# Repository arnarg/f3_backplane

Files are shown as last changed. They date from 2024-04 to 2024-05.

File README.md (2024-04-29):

# F3 Backplane

> F2 + 1 = F3, right?

This is a custom backplane PCB for Terramaster F2-221, which adds a socket for an NVMe SSD for booting an operating system from.

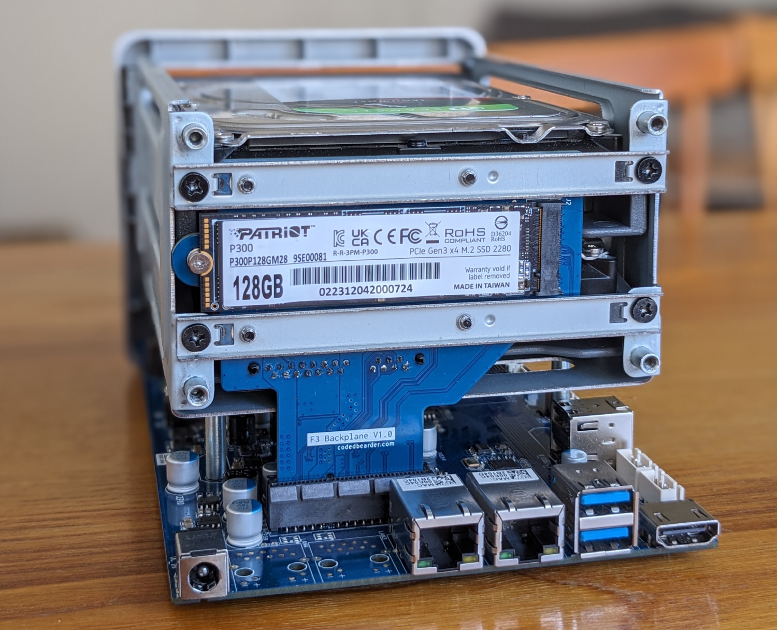
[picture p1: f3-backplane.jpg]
Picture of backplane PCB


Blog post about creating this: https://codedbearder.com/posts/f3-backplane/

## Ordering from JLCPCB

The gerber zip file can be found under `fab/v1.0/f3_backplane.zip` and is generated for JLCPCB. When ordering the PCB make sure to select impedance controlled stackup ***JLC04161H-7628***.

Screenshot of impedance control option selected

Also, make sure to select ***Gold Fingers*** and ***30°finger chamfered***. It will recommend selecting an ENIG surface finish in order to get them _actually_ gold plated, but as this is more expensive and the backplane _shouldn't_ get removed and inserted into the motherboard often I just went with the standard HASL (with lead) surface finish and I haven't had any problems.

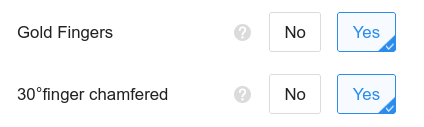
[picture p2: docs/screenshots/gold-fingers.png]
Screenshot of the gold fingers option selected


[Bill of materials](./f3_backplane.csv)

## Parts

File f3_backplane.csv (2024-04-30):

# | Reference | Qty | Value | Footprint | DNP | Digikey Part No.
1 | C1, C2 | 2 | 47uF | Capacitor_SMD:C_0805_2012Metric
2 | C3, C12, C13, C18, C19, C32, C33, C38, C39 | 9 | 22uF | Capacitor_SMD:C_0805_2012Metric
3 | C4, C5, C6, C11, C14, C15, C17, C20, C21, C22, C31, C34, C35, C37, C40, C41, C42 | 17 | 100nF | Capacitor_SMD:C_0603_1608Metric
4 | C10, C16, C30, C36 | 4 | 10uF | Capacitor_SMD:C_0805_2012Metric
5 | J2 | 1 | Bus_M.2_Socket_M | Connector_Backplane:Amphenol_MDT420M01001 |  | MDT420M01001CT-ND
6 | J3, J4 | 2 | SATA_Backplane | Connector_Backplane:Molex_0877011001 |  | WM3587-ND
7 | Q1 | 1 | MMBT3904 | Package_TO_SOT_SMD:SOT-23
8 | R1, R2, R3, R4 | 4 | 2R2 | Resistor_SMD:R_2512_6332Metric
9 | U1, U2, U3, U4 | 4 | NCP45521 | Load_Switches:NCP45521 |  | NCP45521IMNTWG-LOSCT-ND

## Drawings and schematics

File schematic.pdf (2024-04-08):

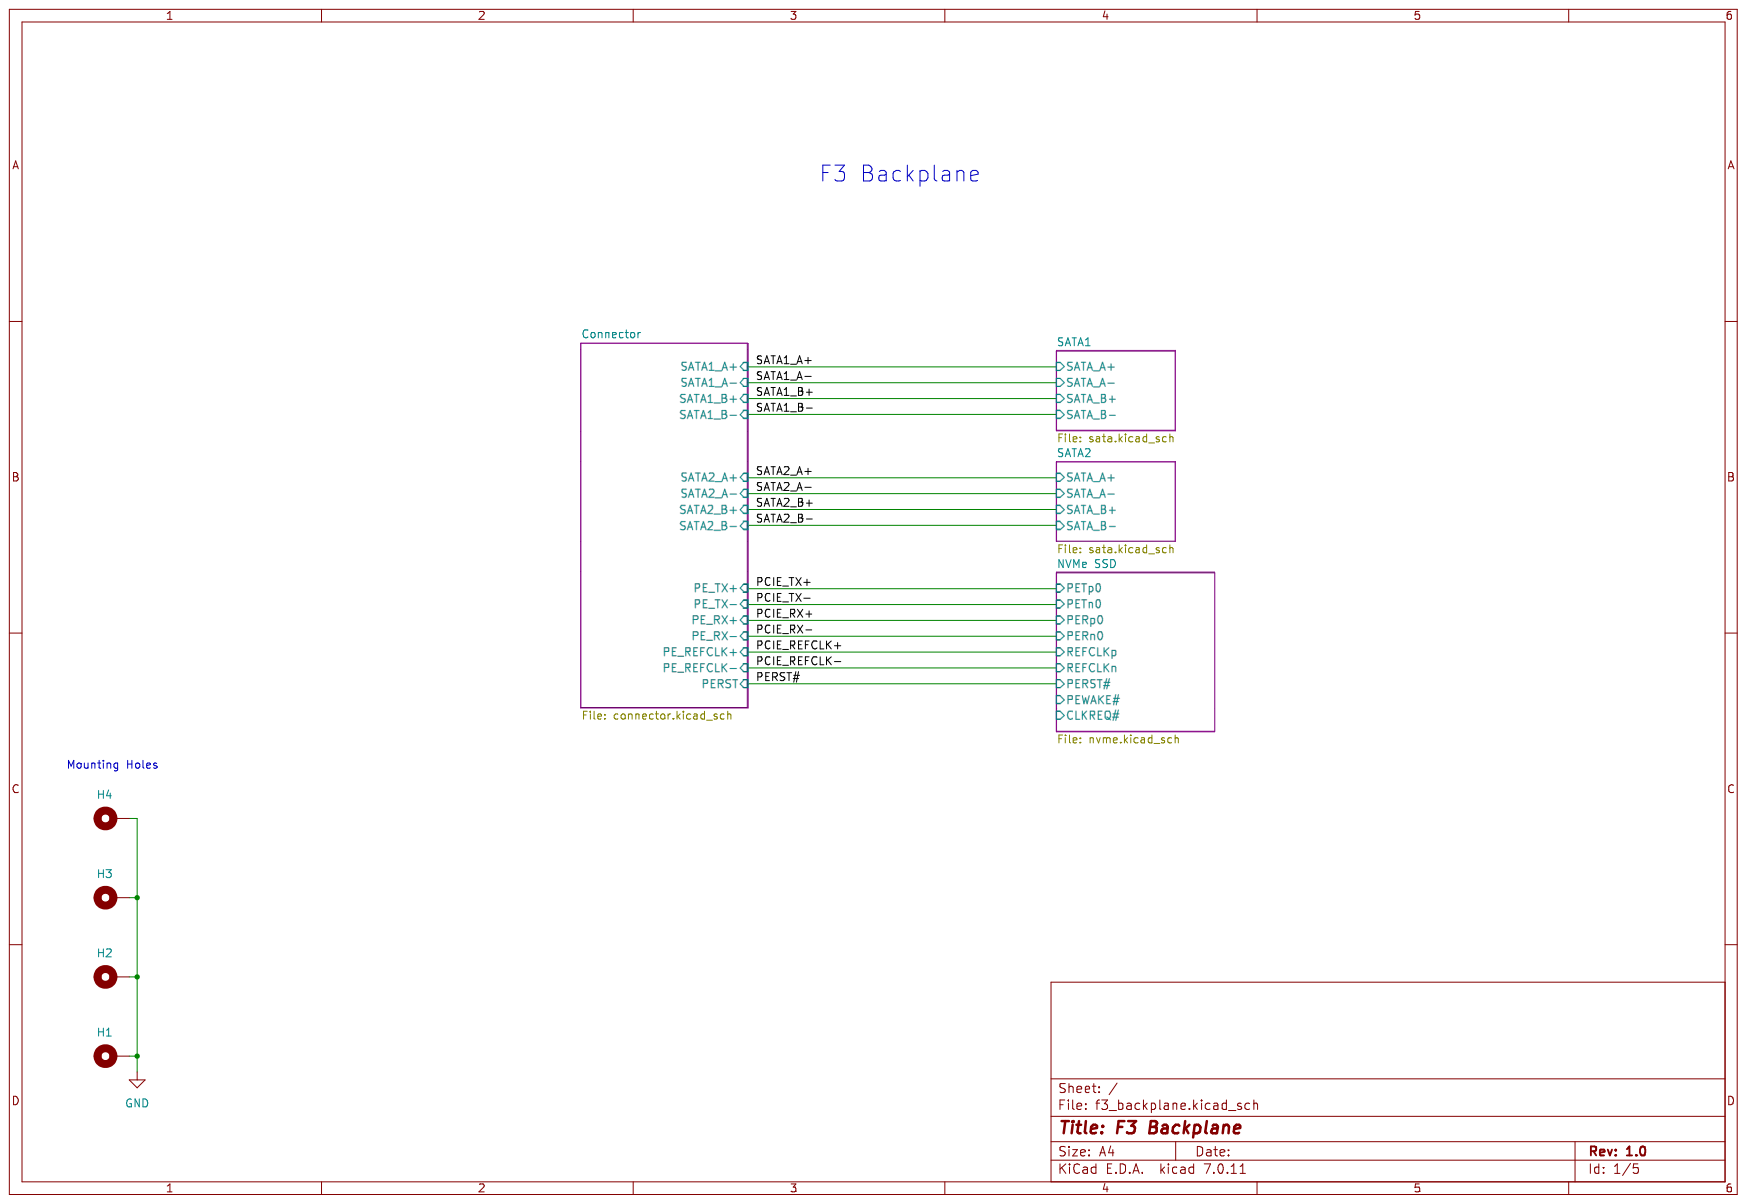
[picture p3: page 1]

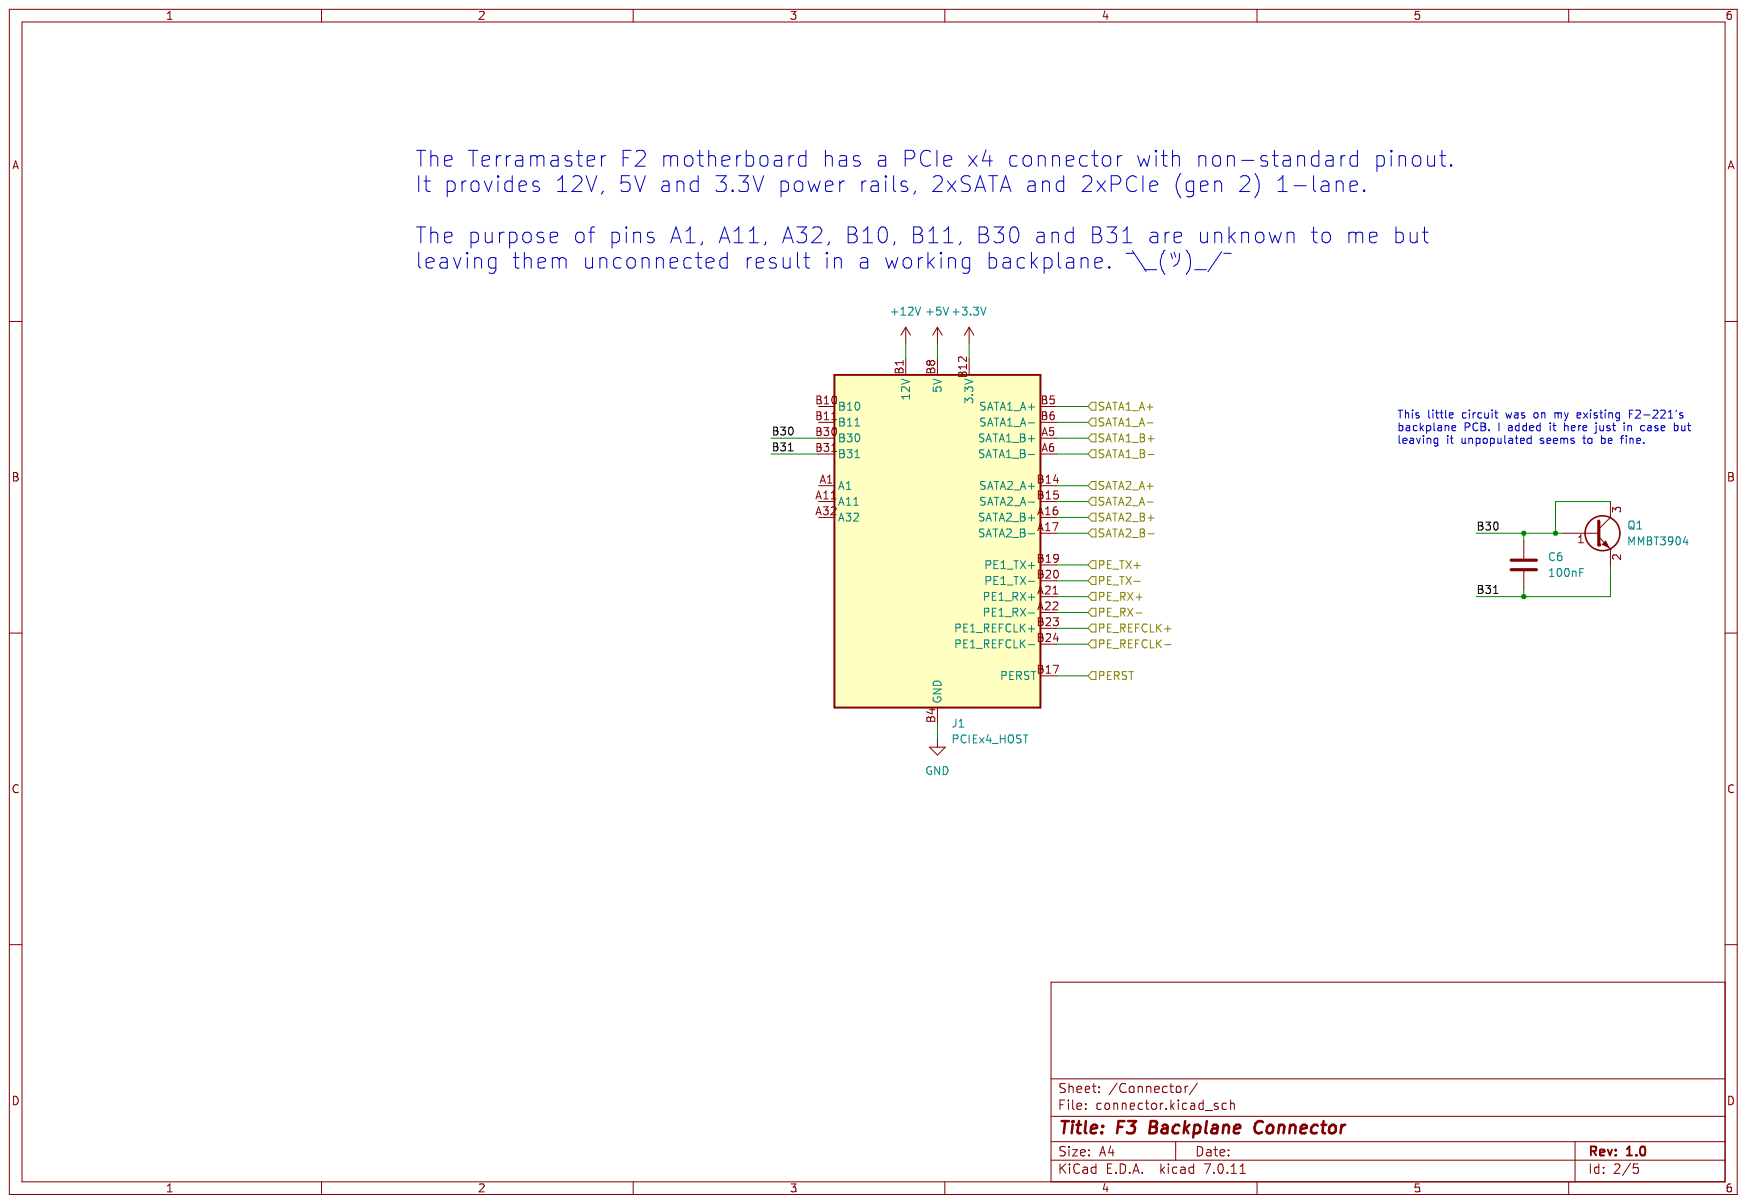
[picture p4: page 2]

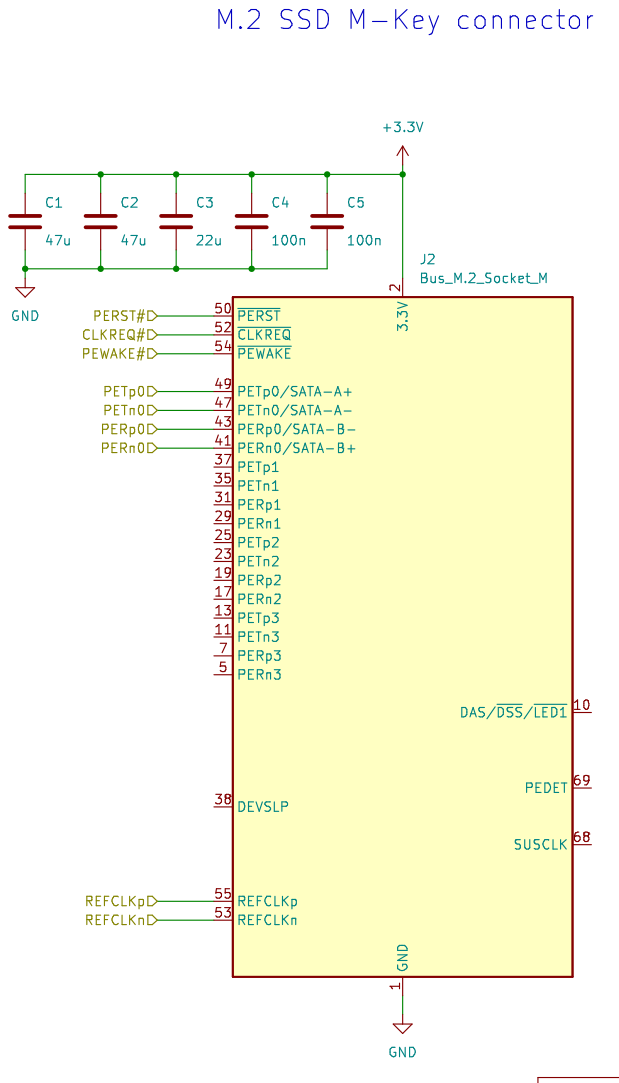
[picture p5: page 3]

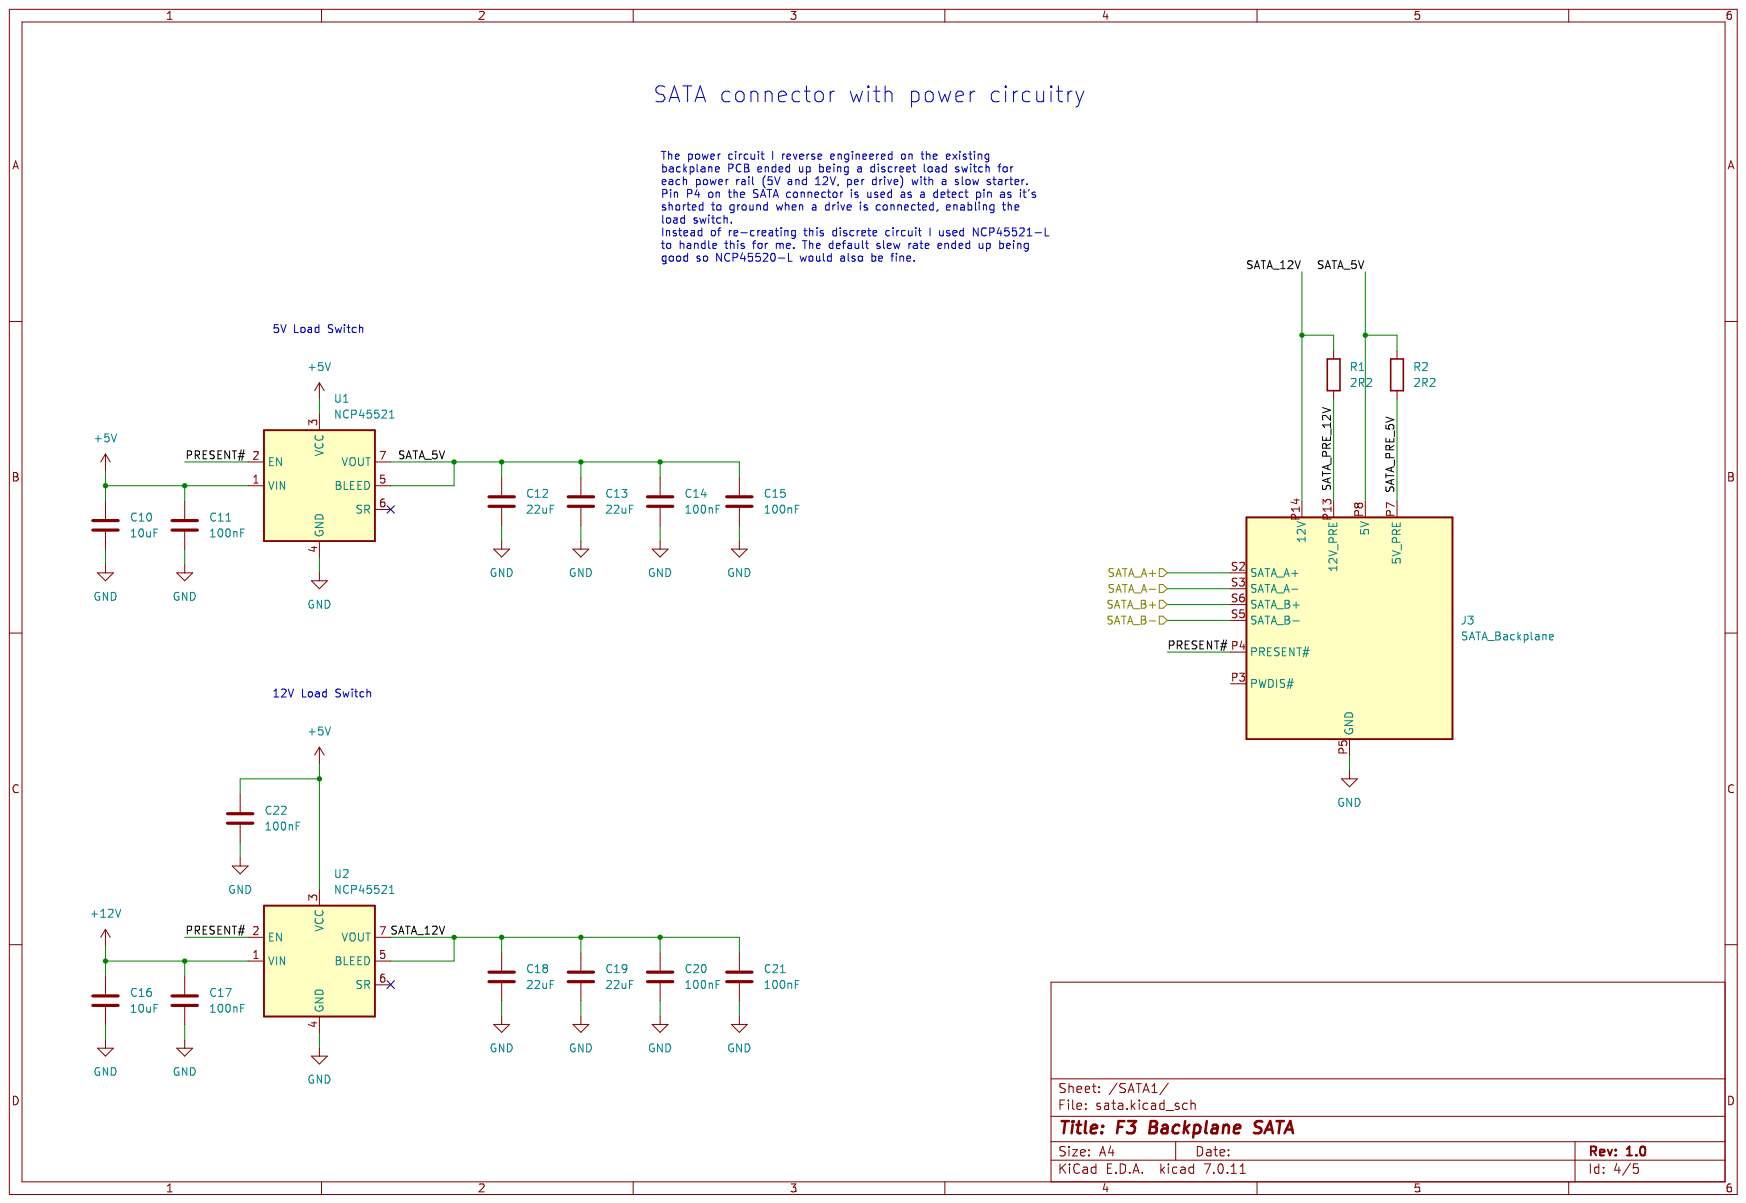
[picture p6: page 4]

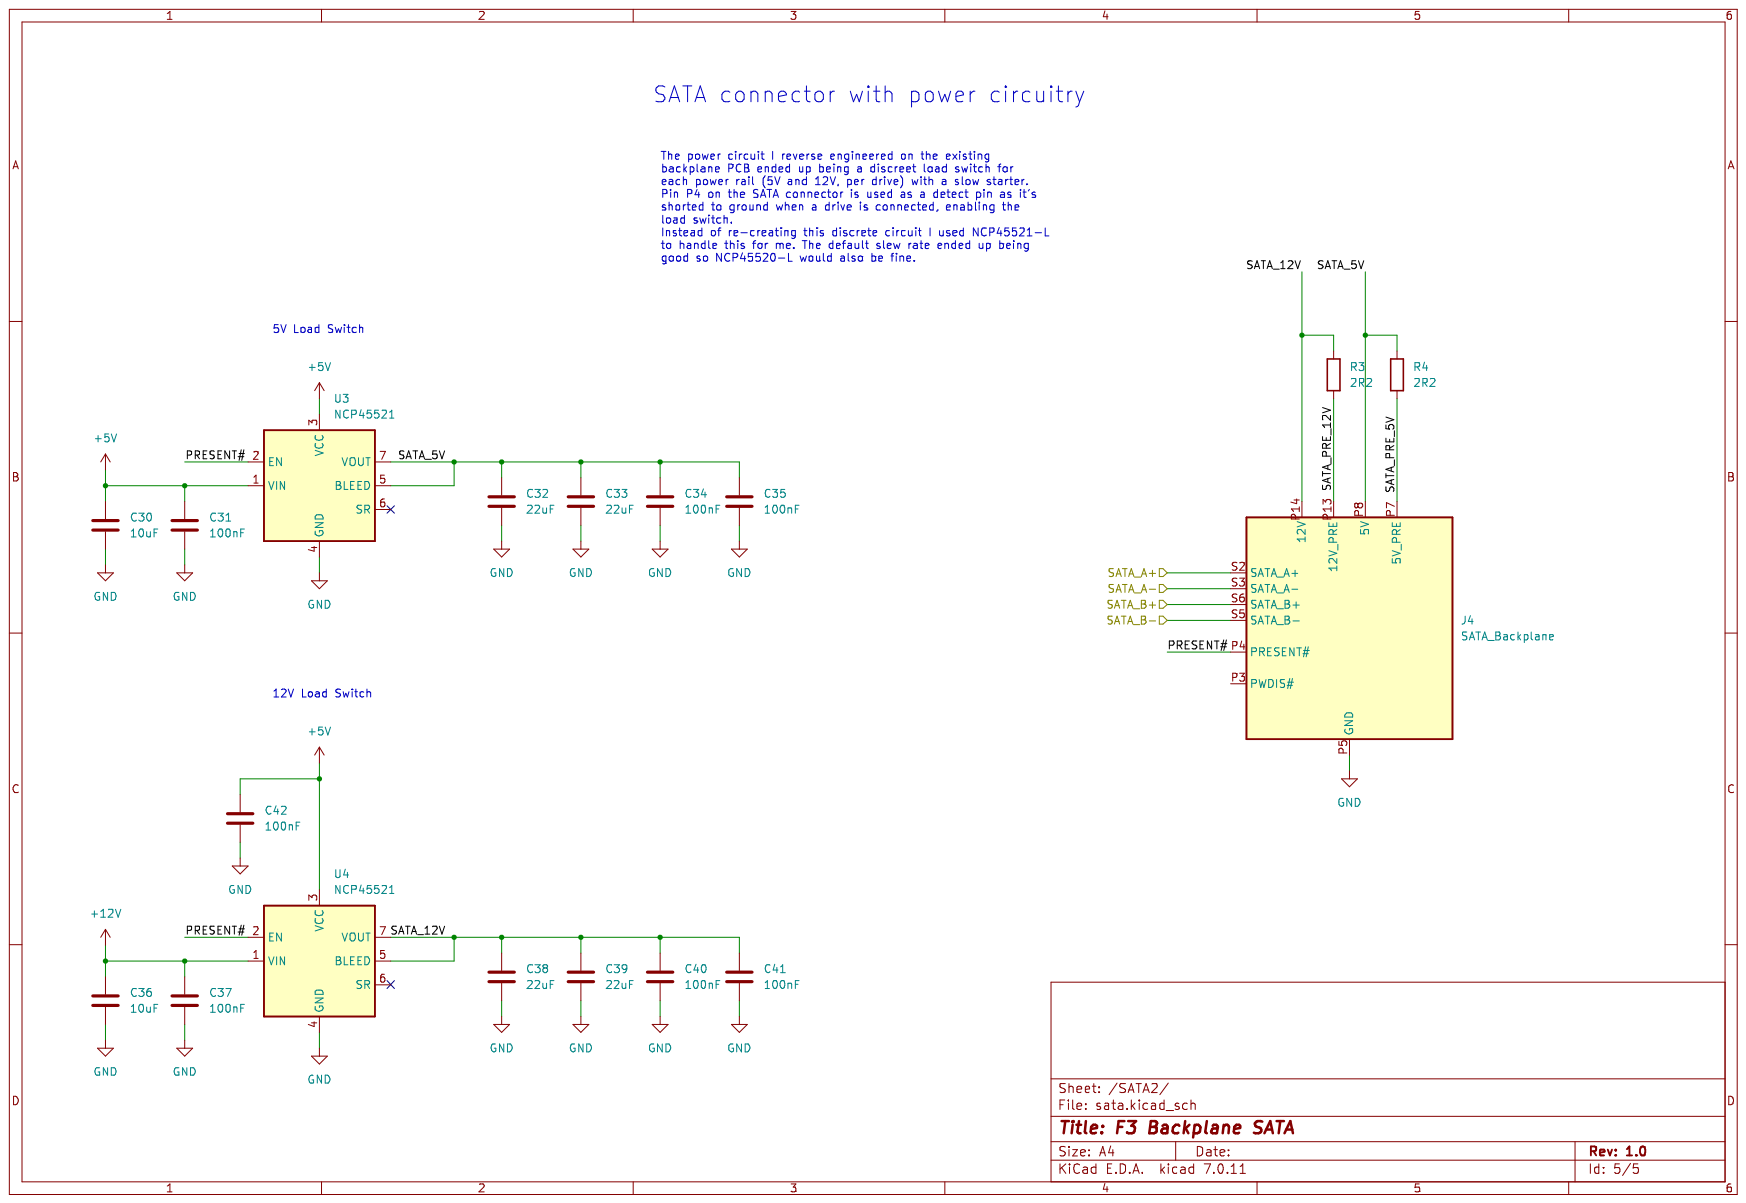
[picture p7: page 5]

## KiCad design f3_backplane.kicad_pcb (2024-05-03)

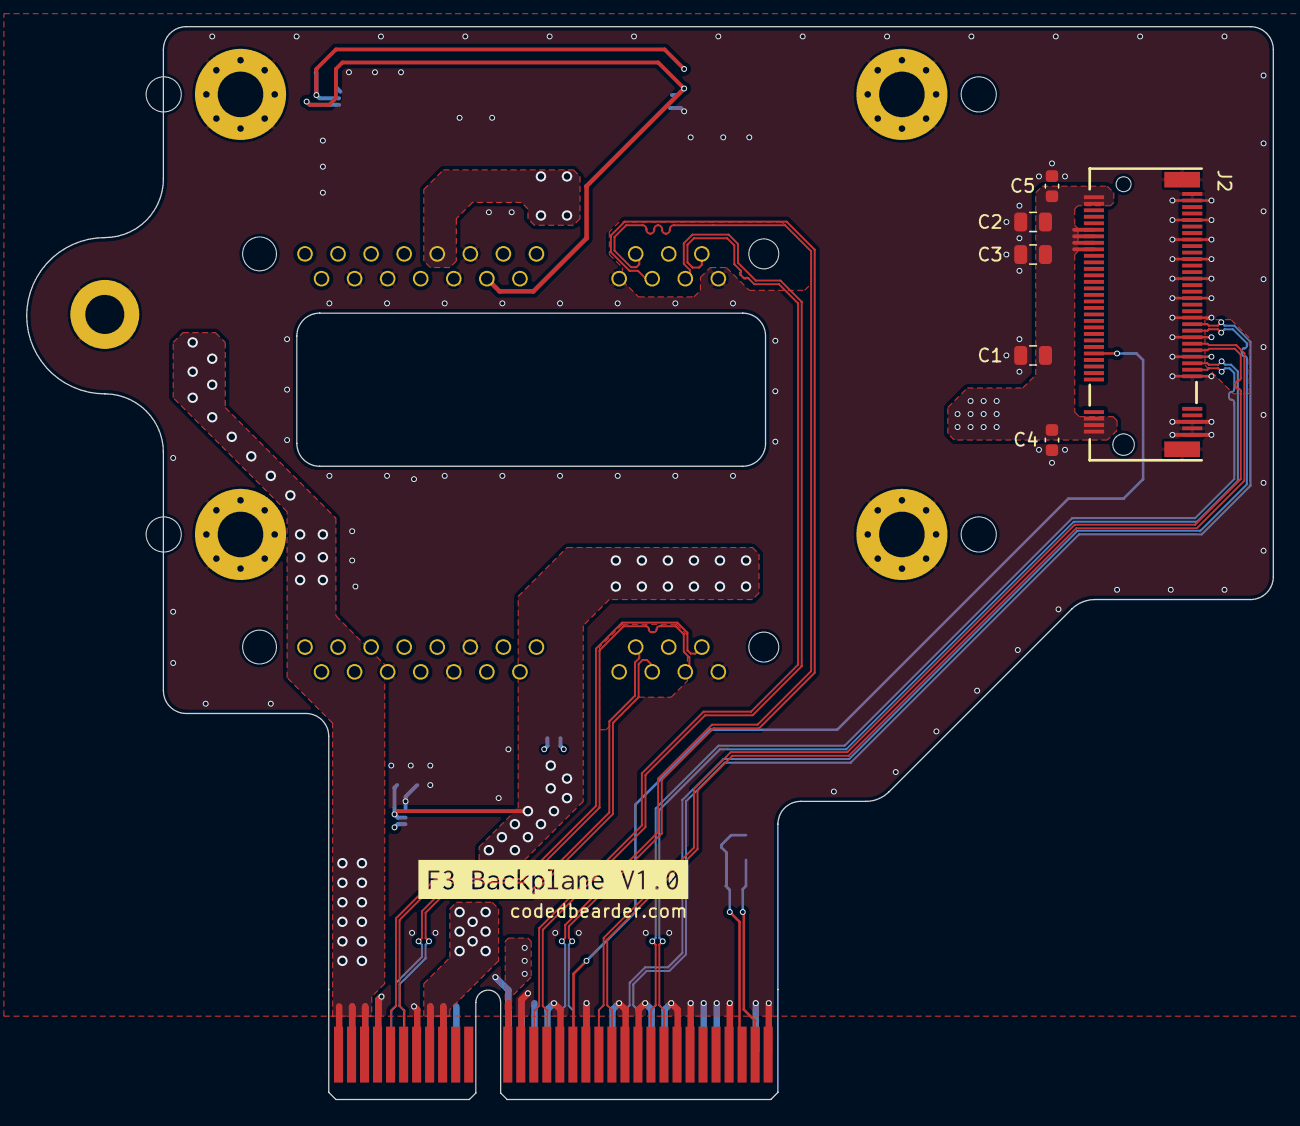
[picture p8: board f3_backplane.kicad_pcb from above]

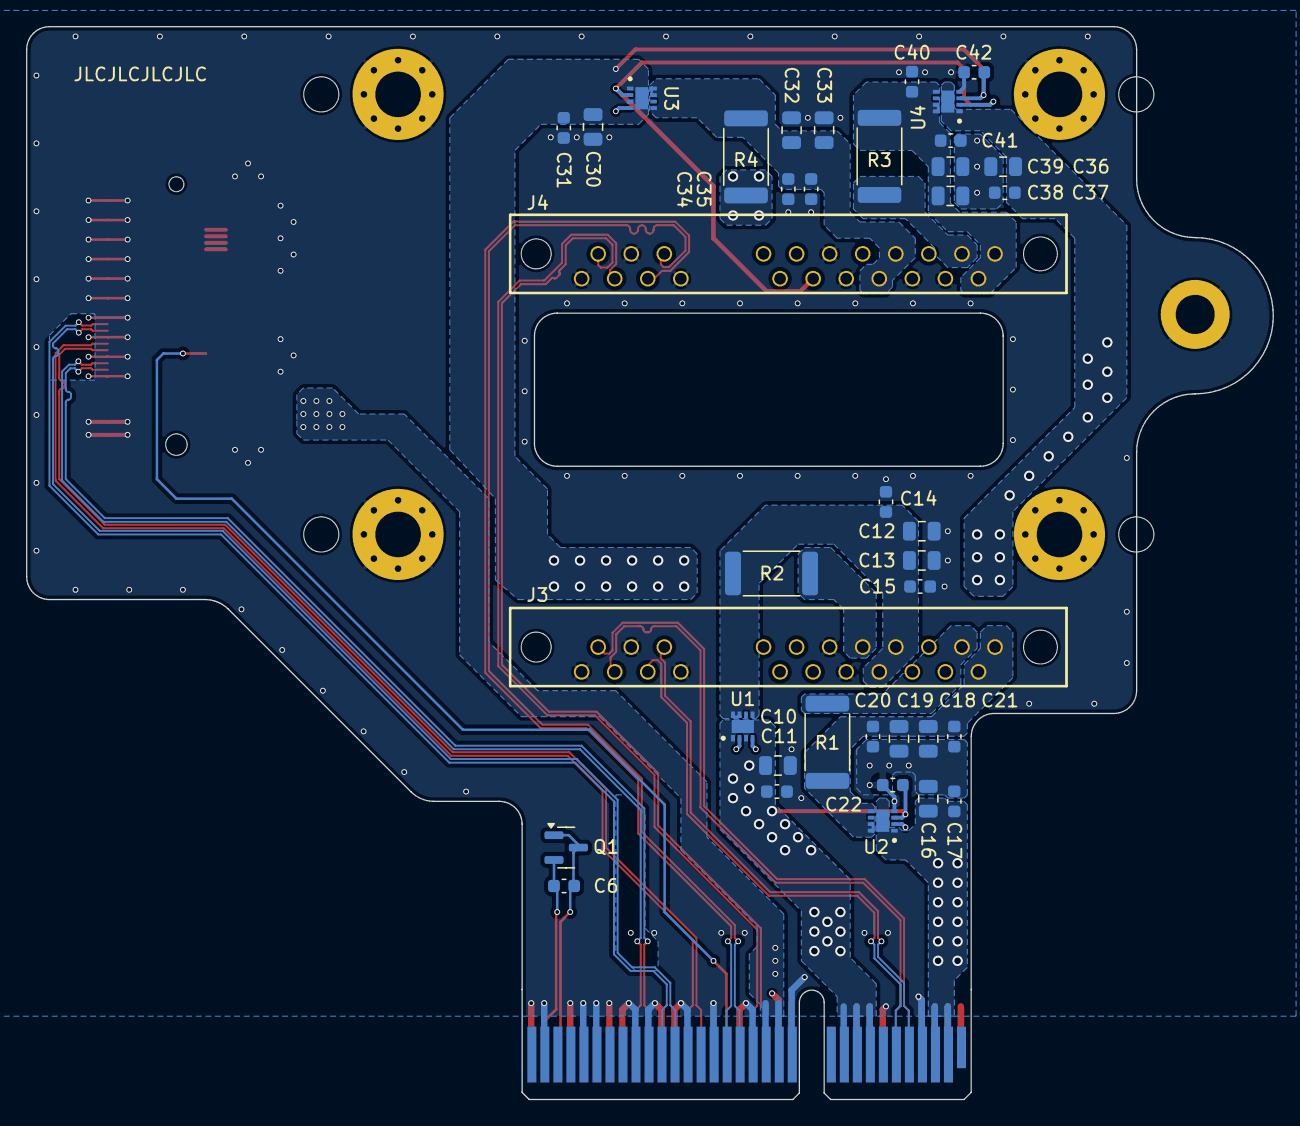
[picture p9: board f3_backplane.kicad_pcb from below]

Board: 4 copper layers, 95.8 x 82.4 mm, 49 parts (38 on the bottom side), 31 nets.

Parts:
C1, C2: 47u; C_0805_2012Metric
C3: 22u; C_0805_2012Metric
C4, C5: 100n; C_0603_1608Metric
C6, C11, C14, C15, C17, C20, C21, C22, C31, C34, C35, C37, C40, C41, C42: 100nF; C_0603_1608Metric
C10, C16, C30, C36: 10uF; C_0805_2012Metric
C12, C13, C18, C19, C32, C33, C38, C39: 22uF; C_0805_2012Metric
H1, H2, H3, H4: MountingHole_Pad; MountingHole_3.5mm_Pad_Via_With_Alignment_Hole
J1: PCIEx4_HOST
J2: Bus_M.2_Socket_M; Amphenol_MDT420M01001
J3, J4: SATA_Backplane; Molex_0877011001
Q1: MMBT3904; SOT-23
R1, R2, R3, R4: 2R2; R_2512_6332Metric
U1, U2, U3, U4: NCP45521

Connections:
+3.3V: C1.1, C2.1, C3.1, C4.1, C5.1, J1.A13 (3.3V), J1.A14 (3.3V), J1.B12 (3.3V), J2.2 (3.3V), J2.4 (3.3V), J2.12 (3.3V), J2.14 (3.3V), J2.16 (3.3V), J2.18 (3.3V), J2.70 (3.3V), J2.72 (3.3V), J2.74 (3.3V)
+5V: C10.1, C11.1, C22.1, C30.1, C31.1, C42.1, J1.A8 (5V), J1.A9 (5V), J1.A10 (5V), J1.B8 (5V), J1.B9 (5V), U1.1 (VIN), U1.3 (VCC), U1.9 (VIN), U2.3 (VCC), U3.1 (VIN), U3.3 (VCC), U3.9 (VIN), U4.3 (VCC)
+12V: C16.1, C17.1, C36.1, C37.1, J1.A2 (12V), J1.A3 (12V), J1.B1 (12V), J1.B2 (12V), J1.B3 (12V), U2.1 (VIN), U2.9 (VIN), U4.1 (VIN), U4.9 (VIN)
/Connector/B30: C6.1, J1.B30, Q1.1 (B), Q1.3 (C)
/Connector/B31: C6.2, J1.B31, Q1.2 (E)
/PCIE_REFCLK+: J1.B23 (PE1_REFCLK+), J2.55 (REFCLKp)
/PCIE_REFCLK-: J1.B24 (PE1_REFCLK-), J2.53 (REFCLKn)
/PCIE_RX+: J1.A21 (PE1_RX+), J2.43 (PERp0/SATA-B-)
/PCIE_RX-: J1.A22 (PE1_RX-), J2.41 (PERn0/SATA-B+)
/PCIE_TX+: J1.B19 (PE1_TX+), J2.49 (PETp0/SATA-A+)
/PCIE_TX-: J1.B20 (PE1_TX-), J2.47 (PETn0/SATA-A-)
/PERST#: J1.B17 (PERST), J2.50 (~PERST)
/SATA1/PRESENT#: J3.P4 (PRESENT#), U1.2 (EN), U2.2 (EN)
/SATA1/SATA_5V: C12.1, C13.1, C14.1, C15.1, J3.P8 (5V), J3.P9 (5V), R2.1, U1.5 (BLEED), U1.7 (VOUT)
/SATA1/SATA_12V: C18.1, C19.1, C20.1, C21.1, J3.P14 (12V), J3.P15 (12V), R1.1, U2.5 (BLEED), U2.7 (VOUT)
/SATA1/SATA_PRE_5V: J3.P7 (5V_PRE), R2.2
/SATA1/SATA_PRE_12V: J3.P13 (12V_PRE), R1.2
/SATA1_A+: J1.B5 (SATA1_A+), J3.S2 (SATA_A+)
/SATA1_A-: J1.B6 (SATA1_A-), J3.S3 (SATA_A-)
/SATA1_B+: J1.A5 (SATA1_B+), J3.S6 (SATA_B+)
/SATA1_B-: J1.A6 (SATA1_B-), J3.S5 (SATA_B-)
/SATA2/PRESENT#: J4.P4 (PRESENT#), U3.2 (EN), U4.2 (EN)
/SATA2/SATA_5V: C32.1, C33.1, C34.1, C35.1, J4.P8 (5V), J4.P9 (5V), R4.1, U3.5 (BLEED), U3.7 (VOUT)
/SATA2/SATA_12V: C38.1, C39.1, C40.1, C41.1, J4.P14 (12V), J4.P15 (12V), R3.1, U4.5 (BLEED), U4.7 (VOUT)
/SATA2/SATA_PRE_5V: J4.P7 (5V_PRE), R4.2
/SATA2/SATA_PRE_12V: J4.P13 (12V_PRE), R3.2
/SATA2_A+: J1.B14 (SATA2_A+), J4.S2 (SATA_A+)
/SATA2_A-: J1.B15 (SATA2_A-), J4.S3 (SATA_A-)
/SATA2_B+: J1.A16 (SATA2_B+), J4.S6 (SATA_B+)
/SATA2_B-: J1.A17 (SATA2_B-), J4.S5 (SATA_B-)
GND: C1.2, C2.2, C3.2, C4.2, C5.2, C10.2, C11.2, C12.2, C13.2, C14.2, C15.2, C16.2, C17.2, C18.2, C19.2, C20.2, C21.2, C22.2, C30.2, C31.2, C32.2, C33.2, C34.2, C35.2, C36.2, C37.2, C38.2, C39.2, C40.2, C41.2, C42.2, H1.1, H2.1, H3.1, H4.1, J1.A4 (GND), J1.A12 (GND), J1.A15 (GND), J1.A18 (GND), J1.A20 (GND), J1.A23 (GND), J1.A24 (GND), J1.A27 (GND), J1.A28 (GND), J1.A31 (GND), J1.B4 (GND), J1.B7 (GND), J1.B13 (GND), J1.B16 (GND), J1.B18 (GND), J1.B21 (GND), J1.B22 (GND), J1.B25 (GND), J1.B26 (GND), J1.B29 (GND), J1.B32 (GND), J2.1 (GND), J2.3 (GND), J2.9 (GND), J2.15 (GND), J2.21 (GND), J2.27 (GND), J2.33 (GND), J2.39 (GND), J2.45 (GND), J2.51 (GND), J2.57 (GND), J2.71 (GND), J2.73 (GND), J2.75 (GND), J3.P5 (GND), J3.P6 (GND), J3.P10 (GND), J3.P12 (GND), J3.S1 (GND), J3.S4 (GND), J3.S7 (GND), J4.P5 (GND), J4.P6 (GND), J4.P10 (GND), J4.P12 (GND), J4.S1 (GND), J4.S4 (GND), J4.S7 (GND), U1.4 (GND), U2.4 (GND), U3.4 (GND), U4.4 (GND)

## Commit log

2024-04-06 More routing
    [f3_backplane.kicad_sch, sata.kicad_sch]
2024-04-07 Routing power
    [f3_backplane.kicad_pcb, sata.kicad_sch]
2024-04-07 Add ground plane to outer layers
    [f3_backplane.kicad_pcb]
2024-04-08 Finish v1.0
    [connector.kicad_sch, f3_backplane.kicad_pcb, f3_backplane.kicad_sch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]
2024-04-26 Add thermal reliefs to internal ground plane
    [f3_backplane.kicad_pcb]
2024-04-29 Add datasheet links and digikey part numbers
    [connector.kicad_sch, f3_backplane.kicad_pcb, f3_backplane.kicad_sch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]
2024-04-29 Generate bill of materials
    [f3_backplane.csv]
2024-04-29 Add README link to bill of materials
2024-04-29 Fix capacitor values
    [f3_backplane.csv, nvme.kicad_sch]
2024-04-30 Remove edge connector from bill of materials
    [connector.kicad_sch, f3_backplane.csv]
2024-05-03 Improve differential pair intra-pair matching
    [f3_backplane.kicad_pcb]
